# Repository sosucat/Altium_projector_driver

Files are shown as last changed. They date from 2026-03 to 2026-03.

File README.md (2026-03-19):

# Altium_projector_driver
Altium project files for a projector driver. 4-layer.
- Connects to
   - Laser (jst-xh): Laser Tree [K60](https://lasertree.com/products/lasertree-k60-60w-40w-20w-power-switchable-laser-module). 24V 60W optical power 4kHz pwm.
   - Galvo (screw): 24V 2A
   - Laser DAC (jst-xh): [Helios DAC](https://bitlasers.com/helios-laser-dac/). 1.68V (3.3V half side) ILDA.
   - 10k thermistors (jst-xh).
   - 24V dc power supply (screw)
- Features
  - Thermal shutoff based on the temperatures of the laser module and galvo driver PCB.
  - P-channel MOSFET switch for Galvo.
  - 1.68V analog to 4kHz 5V pwm conversion + AND gate switch for Laser.
  - LED indicators for the board power, Galvo enable, and Laser enable.
  - ATmega328P.
  - 6-pin ICSP + TTL interface.

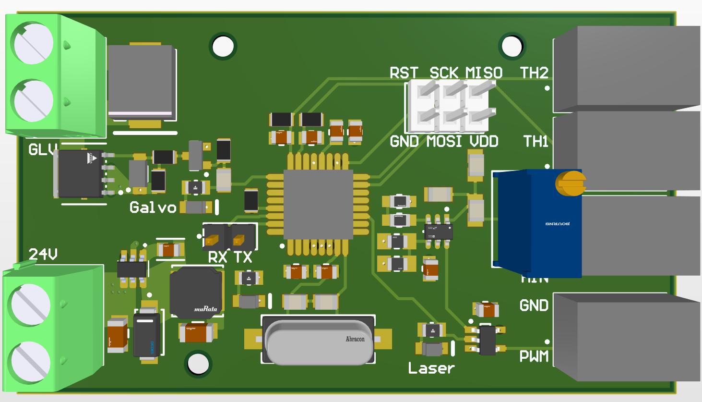
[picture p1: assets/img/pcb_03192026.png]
A rendered image of the circuit board


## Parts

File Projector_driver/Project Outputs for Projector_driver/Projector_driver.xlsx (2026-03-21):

Line # | Name | Description | Designator | Revision ID | Revision State | Revision Status | Quantity | Manufacturer 1 | Manufacturer Part Number 1 | Manufacturer Lifecycle 1 | Supplier 1 | Supplier Part Number 1
 | S2B-XH-A(LF)(SN) | Male Header, Pitch 2.5 mm, 1 x 2 Position, Height 6.1 mm, Tail Length 3.4 mm, -25 to 85 degC, RoHS, Bulk | AIN, Plsr, Pthm1, Pthm2 | CMP-1755-00005-1 | Released | Up to date | 4 | JST | S2B-XH-A(LF)(SN) | Volume Production | Arrow Electronics | S2B-XH-A(LF)(SN)
 | GCM21BR72A104KA37L | Ceramic Capacitor for Automotive 100nF ±10% 100VDC X7R 0805 Embossed T/R | Cand, Caref, Cavcc, Cltc, Cthm1, Cthm2, Cvcc1, Cvcc2 | CMP-2007-03364-2 | New From Design | Up to date | 8 | Murata | GCM21BR72A104KA37L | Volume Production | Avnet | 45Y5182
 | GRM21BR71H474KA88L | Chip Multilayer Ceramic Capacitors for General Purpose, 0805, 0.47uF, X7R, 15%, 10%, 50V | Cboot | CMP-06035-060025-1 | New From Design | Up to date | 1 | Murata | GRM21BR71H474KA88L | Volume Production | Mouser | 81-GRM21BR71H474KA88
 | GRM31CR71H475KA12L | Chip Multilayer Ceramic Capacitors for General Purpose, 1206, 4.7uF, X7R, 15%, 10%, 50V | Cin | CMP-1037-04923-3 | New From Design | Up to date | 1 | Murata | GRM31CR71H475KA12L | Volume Production | Future Electronics | 5114127
 | GRM31CZ71C226ME15L | Chip Multilayer Ceramic Capacitors for General Purpose, 1206, 22uF, X7R, 15%, 10%, 10V | Cout | CMP-06035-003841-1 | New From Design | Up to date | 1 | Murata | GRM31CZ71C226ME15L | Volume Production | Mouser | 81-GRM31CZ71C226ME5L
 | 08055A270FAT2A |  | Cxtal1, Cxtal2 | CMP-2007-04296-1 | Released | Up to date | 2 | KYOCERA AVX | 08055A270FAT2A | Volume Production | Mouser | 581-08055A270FAT2A
 | B160-13-F | DIODE SCHOTTKY 60V 1A SMA | D1 | CMP-2000-05885-2 | New From Design | Up to date | 1 | Diodes Inc. | B160-13-F | Volume Production | Mouser | 621-B160-F
 | B560C-13-F | Schottky Barrier Rectifier, 5 A, 60 V, -55 to 125 degC, 2-Pin SMD, RoHS, Tape and Reel | Dpfet_sch | CMP-2000-05098-2 | Released | Up to date | 1 | Diodes Inc. | B560C-13-F | Volume Production | Mouser | 621-B560C-F
 | MMSZ5245BT1G | Zener Voltage Regulator, 500 mW, 2-Pin SOD-123, Pb-Free, Tape and Reel | Dpfet_zn | CMP-1060-00535-1 | Released | Up to date | 1 | onsemi | MMSZ5245BT1G | Volume Production | Arrow Electronics | MMSZ5245BT1G
 | HSMG-C170 | Chip LED, Green, 2.2 V, -40 to 85 degC, 2-Pin SMD, Pb-Free, Tape and Reel | DSglv, DSlsr, DSpwr | CMP-2000-05062-1 | Released | Up to date | 3 | Broadcom | HSMG-C170 | Volume Production | Mouser | 630-HSMG-C170
 | 1729128 | PCB Terminal Block, 13.5 A, 400 V, 2-Pin THD, RoHS, Bulk | Jglv, Jvin | CMP-2000-05815-1 | Released | Up to date | 2 | Phoenix Contact | 1729128 | Volume Production | Arrow Electronics | 1729128
 | TSW-102-07-F-S | CONN HEADER VERT 2POS 2.54MM | Jttl | CMP-02766-001458-1 | New From Design | Up to date | 1 | Samtec | TSW-102-07-F-S | Volume Production | Avnet | TSW-102-07-F-S
 | LQH5BPN100MT0L | Wire Wound Ferrite Inductor for Power Lines 10μH ±20% 0.1272Ω 1.60A 2020 | L1 | CMP-06042-011567-1 | New From Design | Up to date | 1 | Murata | LQH5BPN100MT0L | Volume Production | Newark | LQH5BPN100MT0L
 | MTSW-103-07-F-D-244 | Modified .025" SQ Post Header, Through-hole, Vertical, -55 to 125 degC, 2.54 mm Pitch, 6-Pin, Male, RoHS | Picsp | CMP-1024-00098-1 | Released | Up to date | 1 | Samtec | MTSW-103-07-F-D-244 | Volume Production | Mouser | 200-MTSW10307FD244
 | 2N7002LT1G | Small Signal MOSFET, 60 V, 115 mA, N-Channel, 3-Pin SOT-23, Pb-Free, Tape and Reel | Qn | CMP-1058-00781-1 | Released | Up to date | 1 | onsemi | 2N7002LT1G | Volume Production | Mouser | 863-2N7002LT1G
 | SQJ459EP-T1_GE3 | MOSFET P-CH 60V 52A POWERPAKSO-8 | Qp | CMP-02550-000107-1 | New From Design | Up to date | 1 | Vishay | SQJ459EP-T1_GE3 | Volume Production | Arrow Electronics | SQJ459EP-T1_GE3
 | RG2012P-105-B-T5 | Automotive Metal Thin Film Chip Resistor, 0805, 1MΩ, 0.1%, 25ppm/°C, 0.125W, 150V | Rdiv1 | CMP-2001-02713-2 | Released | Up to date | 1 | Susumu | RG2012P-105-B-T5 | Volume Production | Mouser | 754-RG2012P-105-B-T5
 | RG2012P-2803-B-T5 | Automotive Metal Thin Film Chip Resistor, 0805, 280kΩ, 0.1%, 25ppm/°C, 0.125W, 150V | Rdiv2 | CMP-2001-02887-2 | Released | Up to date | 1 | Susumu | RG2012P-2803-B-T5 | Volume Production | Newark | RG2012P-2803-B-T5
 | CRCW08051K20FKEA | RES Thick Film, 1.2kΩ, 1%, 0.125W, 100ppm/°C, 0805 | Rled_glv, Rled_lsr, Rpwr | CMP-2001-03607-2 | New From Design | Up to date | 3 | Vishay | CRCW08051K20FKEA | Volume Production | Avnet | 52K9734
 | ERA6AEB9311V |  | Rnet_ain | CMP-2001-00644-1 | Released | Up to date | 1 | Panasonic | ERA6AEB9311V | Volume Production | Mouser | 667-ERA-6AEB9311V
 | ERA6AEB4993V |  | Rnet_bias | CMP-2001-00840-1 | Released | Up to date | 1 | Panasonic | ERA6AEB4993V | Volume Production | Mouser | 667-ERA-6AEB4993V
 | ERA6AEB113V |  | Rnet_gnd | CMP-2001-00586-1 | Released | Up to date | 1 | Panasonic | ERA6AEB113V | Volume Production | Mouser | 667-ERA-6AEB113V
 | ERA-6AEB103V | Metal Film Chip Resistor, High Reliability Type, 0.125 W, +/- 0.1%, -55 to 155 degC, 0805 (2012 Metric), RoHS, Tape and Reel | Rnfet_pd, Rpfet_vd1, Rpfet_vd2, Rreset, Rthm1, Rthm2 | CMP-2001-00582-2 | Released | Up to date | 6 | Panasonic | ERA-6AEB103V | Volume Production | Newark | ERA6AEB103V
 | ERA6AEB331V |  | Rnfet_sf | CMP-2001-00628-1 | Released | Up to date | 1 | Panasonic | ERA-6AEB331V | Volume Production | Arrow Electronics | ERA-6AEB331V
 | 3296W-1-202LF | TRIMMER 2K OHM 0.5W PC PIN TOP | Rpot | CMP-2000-05582-2 | Released | Up to date | 1 | Bourns | 3296W-1-202LF | Volume Production | Avnet | 3296W-1-202LF
 | ERA-6AEB154V | RES 150K OHM 0.1% 1/8W 0805 | Rset1 | CMP-2001-00599-2 | Released | Up to date | 1 | Panasonic | ERA-6AEB154V | Volume Production | Arrow Electronics | ERA-6AEB154V
 | ERA-6AEB473V |  | Rset2 | CMP-2001-00645-2 | Released | Up to date | 1 | Panasonic | ERA-6AEB473V | Volume Production | Avnet | 08N2176
 | LMR16006YQ5DDCRQ1 | Automotive Qualified SIMPLE SWITCHERÂ® 40V (65V transient), 0.6A Buck Regulator with 28Î¼A IQ | U1 |  | Not managed |  | 1
 | ATmega328P-AU | 8-bit AVR Microcontroller, 32KB Flash, 1KB EEPROM, 2KB SRAM, 32-pin TQFP, Industrial Grade (-40°C to 85°C) | U2 | CMP-0095-00269-2 | Released | Up to date | 1 | Microchip | ATMEGA328P-AU | Volume Production | Arrow Electronics | ATMEGA328P-AU
 | SN74LVC1G08DBVR | Single 2-Input Positive-AND Gate, DBV0005A, LARGE T&R | U3 | CMP-0859-00053-3 | Released | Up to date | 1 | Texas Instruments | SN74LVC1G08DBVR | Volume Production | Mouser | 595-SN74LVC1G08DBVR
 | LTC6992MPS6-1#TRMPBF | IC OSC SILICON PROG TSOT23-6 | U4 | CMP-09075-000003-1 | New From Design | Up to date | 1 | Analog Devices | LTC6992MPS6-1#TRMPBF | Volume Production | Newark | LTC6992MPS6-1#TRMPBF
 | ABLS-16.000MHZ-K4T | CRYSTAL 16.0000MHZ 18PF SMD | Yxtal | CMP-27762-000003-1 | New From Design | Up to date | 1 | Abracon | ABLS-16.000MHZ-K4T | Volume Production | Arrow Electronics | ABLS-16.000MHZ-K4T

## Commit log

2026-02-12 finished the buck convertor
    [Sheet1.SchDoc]
2026-02-21 Implemented the whole schematics
    [PCB1.PcbDoc, Sheet1.SchDoc]
2026-02-23 Arranged the components
    [NetTie.PcbLib, NetTie.SchLib, PCB1.PcbDoc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]
2026-02-23 Added some traces
    [PCB1.PcbDoc, Sheet1.SchDoc]
2026-03-07 I think I made some progress in routing
    [PCB1.PcbDoc, Projector_driver.PrjPcb]
2026-03-18 shrank the board size
    [PCB1.PcbDoc, Sheet1.SchDoc]
2026-03-18 Done routing
    [PCB1.PcbDoc, Sheet1.SchDoc]
2026-03-19 Finished routing and added the readme
    [PCB1.PcbDoc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]
2026-03-21 Changed the crystal caps and cout. Added the BoM doc and excel.
    [PCB1.PcbDoc, Projector_driver.xlsx, Sheet1.SchDoc]
2026-03-23 Changed the internal power planes to signal planes.
    [PCB1.PcbDoc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]
2026-03-23 fab output
    [PCB1_Copper_Plane_1.gbr, PCB1_Copper_Plane_2.gbr]
2026-03-23 project save
    [Projector_driver.PrjPcb]
